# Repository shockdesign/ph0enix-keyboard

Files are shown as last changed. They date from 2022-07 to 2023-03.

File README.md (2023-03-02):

# ph0enix-keyboard

A 40% keyboard consisting of 44 keys.

My attempt of minimising a keyboard but keeping the ability to have some
dedicated arrow keys.

Firmware is currently for KMK as the board is setup to be able to solder a
Raspberry Pi Pico to it.

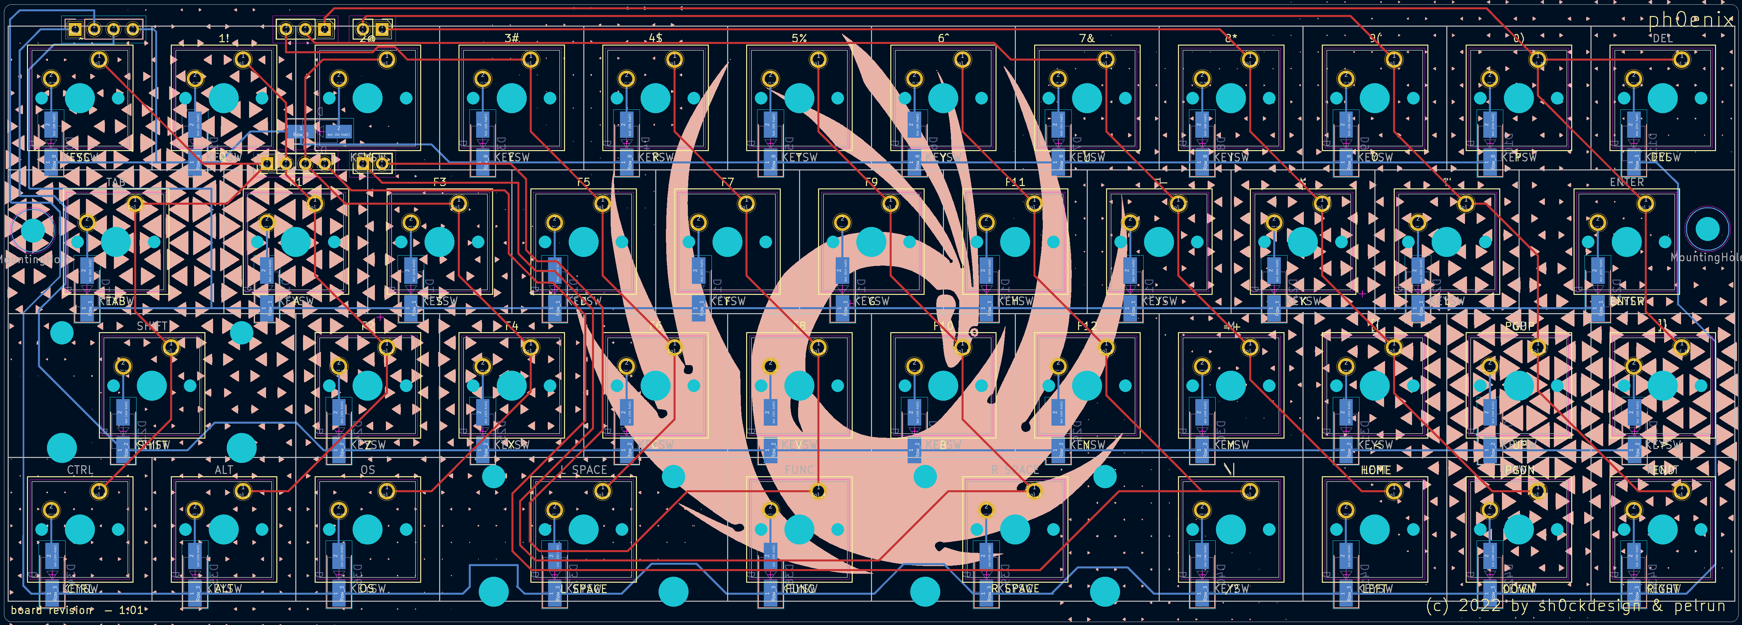
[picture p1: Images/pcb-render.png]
PCB


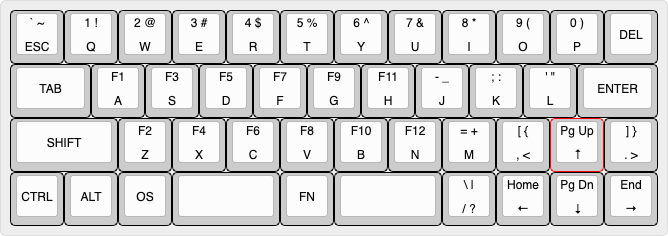
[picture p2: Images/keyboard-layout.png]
Keyboard Layout


### Parts

| Quantity | Part name | Link |
|---|---|---|
| 1 | ph0enix PCB | |
| 44 | SMA Diodes | https://www.lcsc.com/product-detail/_Yint-_C2920036.html |
| 1 | Raspberry Pi Pico | |
| 1 | Micro USB cable | |
| 44 | MX style switches | |
| 1 | 40 pin male header | |
| 1 | 40 pin female header | (optional) |

License in play is CERN-OHL-W-2.0.

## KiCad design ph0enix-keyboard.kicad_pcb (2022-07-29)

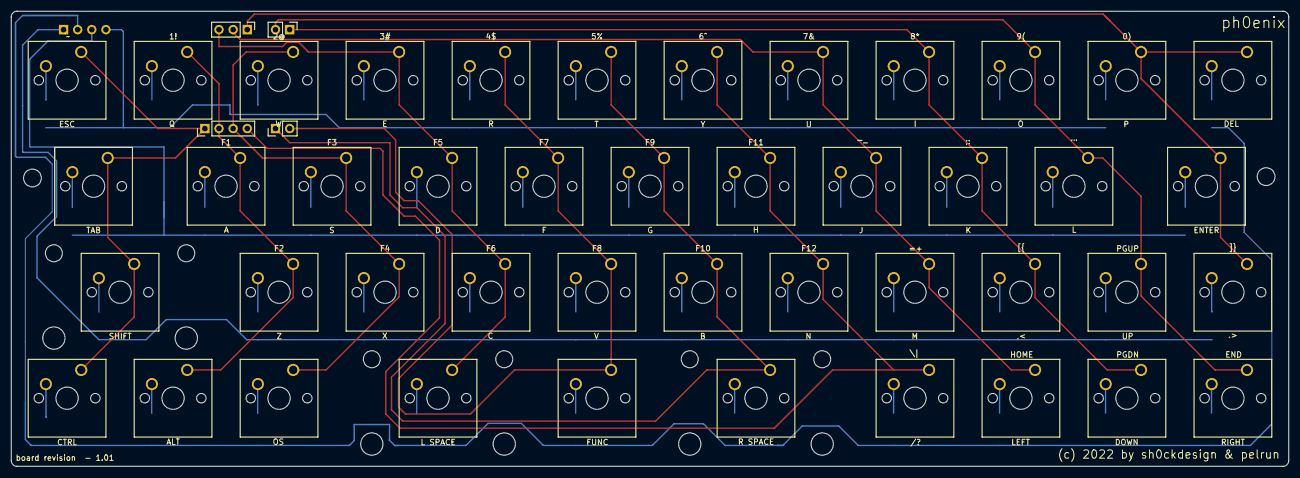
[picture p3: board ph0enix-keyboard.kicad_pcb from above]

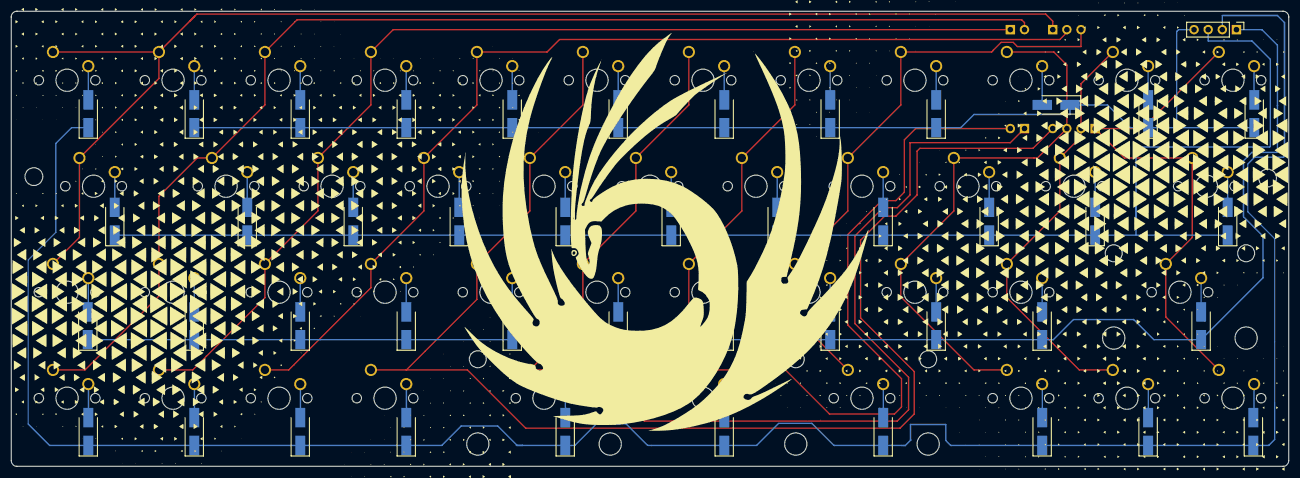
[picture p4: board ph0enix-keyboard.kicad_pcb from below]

Board: 2 copper layers, 229.6 x 81.8 mm, 90 parts (44 on the bottom side), 59 nets.

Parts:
0), 1!, 2@, 3#, 4$, 5%, 6^, 7&, 8*, 9(: KEYSW; SW_Cherry_MX_1.00u_PCB
ALT: KEYSW; SW_Cherry_MX_1.00u_PCB
CTRL: KEYSW; SW_Cherry_MX_1.00u_PCB
D1, D2, D3, D4, D5, D6, D7, D8, D9, D10, D11, D12, D13, D14, D15, D16, D17, D18, D19, D20, D21, D22, D23, D24, D25, D26, D27, D28, D29, D30, D31, D32, D33, D35, D36, D37, D38, D39, D40, D41, D42, D43: D; D_SMA_Handsoldering
DEL: KEYSW; SW_Cherry_MX_1.00u_PCB
DOWN: KEYSW; SW_Cherry_MX_1.00u_PCB
ENTER: KEYSW; SW_Cherry_MX_1.50u_PCB
F1, F2, F3, F4, F5, F6, F7, F8, F9, F10, F11, F12: KEYSW; SW_Cherry_MX_1.00u_PCB
FUNC: KEYSW; SW_Cherry_MX_1.00u_PCB
H1, H2: MountingHole; MountingHole_3.2mm_M3_DIN965
J: KEYSW; SW_Cherry_MX_1.00u_PCB
K: KEYSW; SW_Cherry_MX_1.00u_PCB
L: KEYSW; SW_Cherry_MX_1.00u_PCB
L SPACE: KEYSW; SW_Cherry_MX_2.00u_PCB
LEFT: KEYSW; SW_Cherry_MX_1.00u_PCB
M: KEYSW; SW_Cherry_MX_1.00u_PCB
OS: KEYSW; SW_Cherry_MX_1.00u_PCB
R SPACE: KEYSW; SW_Cherry_MX_2.00u_PCB
RIGHT: KEYSW; SW_Cherry_MX_1.00u_PCB
SHIFT: KEYSW; SW_Cherry_MX_2.00u_PCB
TAB: KEYSW; SW_Cherry_MX_1.50u_PCB
UP: KEYSW; SW_Cherry_MX_1.00u_PCB
[{: KEYSW; SW_Cherry_MX_1.00u_PCB
\|: KEYSW; SW_Cherry_MX_1.00u_PCB
]}: KEYSW; SW_Cherry_MX_1.00u_PCB
`~: KEYSW; SW_Cherry_MX_1.00u_PCB
locked: D; D_SMA_Handsoldering
locked#2: D; D_SMA_Handsoldering

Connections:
/Col_0: CTRL.1, SHIFT.1, TAB.1, `~.1
/Col_1: 1!.1, ALT.1, F1.1, F2.1
/Col_2: 2@.1, F3.1, F4.1, OS.1
/Col_3: 3#.1, F5.1, F6.1, L SPACE.1
/Col_4: 4$.1, F7.1, F8.1, FUNC.1
/Col_5: 5%.1, F9.1, F10.1, R SPACE.1
/Col_6: 6^.1, F11.1, F12.1, \|.1
/Col_7: 7&.1, J.1, LEFT.1, M.1
/Col_8: 8*.1, DOWN.1, K.1, [{.1
/Col_9: 9(.1, L.1, RIGHT.1, UP.1
/Col_10: 0).1, DEL.1, ENTER.1, ]}.1
/Row_0: D1.1 (K), D2.1 (K), D3.1 (K), D4.1 (K), D5.1 (K), D6.1 (K), D7.1 (K), D8.1 (K), D9.1 (K), D10.1 (K), locked.1 (K)
/Row_1: D12.1 (K), D13.1 (K), D14.1 (K), D15.1 (K), D16.1 (K), D17.1 (K), D18.1 (K), D19.1 (K), D20.1 (K), D21.1 (K), D22.1 (K)
/Row_2: D23.1 (K), D24.1 (K), D25.1 (K), D26.1 (K), D27.1 (K), D28.1 (K), D29.1 (K), D30.1 (K), D31.1 (K), D32.1 (K), D33.1 (K)
/Row_3: D11.1 (K), D35.1 (K), D36.1 (K), D37.1 (K), D38.1 (K), D39.1 (K), D40.1 (K), D41.1 (K), D42.1 (K), D43.1 (K), locked#2.1 (K)
unnamed: `~.2, locked.2 (A)
unnamed: 1!.2, D1.2 (A)
unnamed: 2@.2, D2.2 (A)
unnamed: 3#.2, D3.2 (A)
unnamed: 4$.2, D4.2 (A)
unnamed: 5%.2, D5.2 (A)
unnamed: 6^.2, D6.2 (A)
unnamed: 7&.2, D7.2 (A)
unnamed: 8*.2, D8.2 (A)
unnamed: 9(.2, D9.2 (A)
unnamed: 0).2, D10.2 (A)
unnamed: D11.2 (A), DEL.2
unnamed: D12.2 (A), TAB.2
unnamed: D13.2 (A), F1.2
unnamed: D14.2 (A), F3.2
unnamed: D15.2 (A), F5.2
unnamed: D16.2 (A), F7.2
unnamed: D17.2 (A), F9.2
unnamed: D18.2 (A), F11.2
unnamed: D19.2 (A), J.2
unnamed: D20.2 (A), K.2
unnamed: D21.2 (A), L.2
unnamed: D22.2 (A), ENTER.2
unnamed: D23.2 (A), SHIFT.2
unnamed: D24.2 (A), F2.2
unnamed: D25.2 (A), F4.2
unnamed: D26.2 (A), F6.2
unnamed: D27.2 (A), F8.2
unnamed: D28.2 (A), F10.2
unnamed: D29.2 (A), F12.2
unnamed: D30.2 (A), M.2
unnamed: D31.2 (A), [{.2
unnamed: D32.2 (A), UP.2
unnamed: D33.2 (A), ]}.2
unnamed: CTRL.2, locked#2.2 (A)
unnamed: ALT.2, D35.2 (A)
unnamed: D36.2 (A), OS.2
unnamed: D37.2 (A), L SPACE.2
unnamed: D38.2 (A), FUNC.2
unnamed: D39.2 (A), R SPACE.2
unnamed: D40.2 (A), \|.2
unnamed: D41.2 (A), LEFT.2
unnamed: D42.2 (A), DOWN.2
unnamed: D43.2 (A), RIGHT.2

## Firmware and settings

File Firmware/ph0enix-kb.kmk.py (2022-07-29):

# ph0enix designed by shockdesign & pelrun
# https://github.com/shockdesign/ph0enix-keyboard
# Requires CircuitPython 7.0.0 to support the RP2040 MCU
import board

from kmk.kmk_keyboard import KMKKeyboard
from kmk.keys import KC
from kmk.modules.layers import Layers
from kmk.scanners import DiodeOrientation

keyboard = KMKKeyboard()
keyboard.modules.append(Layers())

# keyboard.debug_enabled = True

keyboard.col_pins = (
    board.GP21, board.GP20, board.GP19, board.GP11, board.GP16, board.GP17, board.GP18,
    board.GP12, board.GP15, board.GP14, board.GP13
)
keyboard.row_pins = (board.GP5, board.GP4, board.GP2, board.GP3)

keyboard.diode_orientation = DiodeOrientation.COL2ROW

FN = KC.MO(1)

keyboard.keymap = [
    # Qwerty
    # ,----------------------------------------------------------------------------.
    # | ESC  |   Q  |   W  |   E  |   R  |   T  |   Y  |   U  |   I  |   O  |   P  |
    # |------+------+------+------+------+------+------+------+------+------+------|
    # | Tab  |   A  |   S  |   D  |   F  |   G  |   H  |   J  |   K  |   L  | Enter|
    # |------+------+------+------+------+-------------+------+------+------+------|
    # | Shift|   Z  |   X  |   C  |   V  |   B  |   N  |   M  |   ,  |   Up |   .  |
    # |------+------+------+------+------+------+------+------+------+------+------|
    # | Ctrl |  Alt |  GUI | Space|   FN | Space|   /  | Left | Down | Right| Bksp |
    # `----------------------------------------------------------------------------'
    [
        KC.ESC,   KC.Q,    KC.W,    KC.E,    KC.R,    KC.T,   KC.Y,    KC.U,    KC.I,    KC.O,    KC.P,
        KC.TAB,   KC.A,    KC.S,    KC.D,    KC.F,    KC.G,   KC.H,    KC.J,    KC.K,    KC.L,    KC.ENT,
        KC.LSFT,  KC.Z,    KC.X,    KC.C,    KC.V,    KC.B,   KC.N,    KC.M,    KC.COMM, KC.UP,   KC.DOT,
        KC.LCTRL, KC.LALT, KC.LGUI, KC.SPC,  FN,      KC.SPC, KC.SLSH, KC.LEFT, KC.DOWN, KC.RGHT, KC.BSPC,
    ],
    # Alt
    # ,----------------------------------------------------------------------------.
    # | Grave|   1  |   2  |   3  |   4  |   5  |   6  |   7  |   8  |   9  |   0  |
    # |------+------+------+------+------+------+------+------+------+------+------|
    # | Trans|   F1 |   F3 |   F5 |   F7 |   F9 |  F11 |   -  |   ;  |   '  | Trans|
    # |------+------+------+------+------+-------------+------+------+------+------|
    # | Trans|   F2 |   F4 |   F6 |   F8 |  F10 |  F12 |   =  |   (  | Pg Up|   )  |
    # |------+------+------+------+------+------+------+------+------+------+------|
    # | Trans| Trans| Trans| Trans| Trans| Trans|   \  | Home | Pg Dn|  End |  Del |
    # `----------------------------------------------------------------------------'
    [
        KC.GRV,  KC.N1,   KC.N2,   KC.N3,    KC.N4,   KC.N5,   KC.N6,   KC.N7,   KC.N8,   KC.N9,   KC.N0,
        KC.TRNS, KC.F1,   KC.F3,   KC.F5,    KC.F7,   KC.F9,   KC.F11,  KC.MINS, KC.SCLN, KC.QUOT, KC.TRNS,
        KC.TRNS, KC.F2,   KC.F4,   KC.F6,    KC.F8,   KC.F10,  KC.F12,  KC.EQL,  KC.LBRC, KC.PGUP, KC.RBRC,
        KC.TRNS, KC.TRNS, KC.TRNS, KC.TRNS,  KC.TRNS, KC.TRNS, KC.BSLS, KC.HOME, KC.PGDN, KC.END,  KC.DEL,
    ],
]

if __name__ == '__main__':
    keyboard.go()

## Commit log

2022-07-29 Commit of board, revision 1.01 ready for production
    [ph0enix-keyboard.kicad_pcb]
2023-05-15 Added sample boot.py

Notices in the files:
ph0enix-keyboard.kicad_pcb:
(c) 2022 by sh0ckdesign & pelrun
